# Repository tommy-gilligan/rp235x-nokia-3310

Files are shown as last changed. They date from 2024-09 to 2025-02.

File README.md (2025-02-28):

# Brique: RP235x Nokia 3310 Adapter Board

This started as a cute "what if?":

> What if I could type out messages on my smart phone by using tactile buttons like I used to have on my phone back in high school?

Because the board would need to fit into the chassis of a Nokia 3310 and because there are existing doodads that would be sitting alongside the board anyways, scope has crept to include connecting to these other thingamajigs.

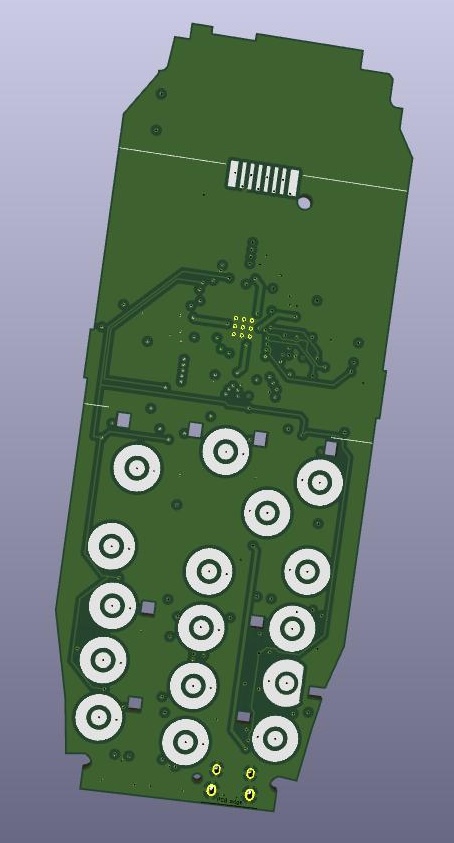
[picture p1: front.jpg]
3D render of front of adapter board

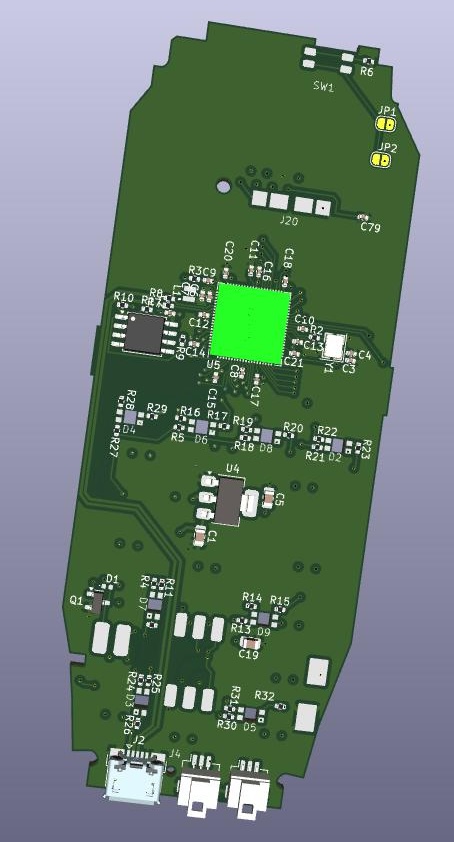
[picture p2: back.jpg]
3D render of back of adapter board


## [Simulation](https://tommy-gilligan.github.io/brique/simulation)
## [API](https://tommy-gilligan.github.io/brique/doc/shared)

## Setting up web environment

## Setting up rp environment

## Setting up board
### Ordering Board
### Disassemble 3310
### Install Hardware Test Program
### Reassemble 3310
### Manual Test
### Install Custom Software

### TODO
#### v0.3
- create example that plays RTTTL (and writes it to screen)
- Snake
- USB text entry

- power button (digital latch.  can this be triggered by 'any key'?  ie. any keypad press turns the device on.  there's enough GPIO to spare that we should have a dedicated GPIO for any key too)
- double check power regulation, boot button
- backlight LEDs (many options but prudent to go with whatever uses least power, is simplest.  use transistor to drive LED directly from battery/power)
- add back supercap rtc
- add jlcpcb part numbers, 3d models
- double check usb footprint
- pass more KiCAD checks in CI

- terse, unfriendly instructions (ie. README)
- document app API

#### Later
- make all system work live on primary core.  give apps dedicated secondary core.
- optional pico-w for wifi/bluetooth (using a module avoids need for recertification?)
    - looks like RP will release such a module (RM2) so go ahead with designing with that in mind
- detect battery type to refuse NiMH
- battery gauge
- mic connection
- use text_input for inputing secret for TOTP (drives the need for inputting numeric digits easily and RTC)
- power button used for BOOT/RUN?
- how should software versions synchronize with hardware versions. what level of compatibility should be supported.
- institute changelog
- use 'Issues' instead of README for tracking
- USB on simulated device
- optimise GPIO pin mapping.  shorten traces etc.
- connection plate for 3d printing
- increase flash capacity? i'd prefer to remove this part altogether by using rp2354 due for release later in the year
- bring more rigour to 'scheduler'

#### Much Later
- flex pcb for keypad?
- LTE modem?
- e-ink display?

https://serdisplib.sourceforge.net/ser/pcd8544.html

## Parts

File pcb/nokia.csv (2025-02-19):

Designator | Footprint | Comment | JLCPCB Part #
C12,C18,C11,C16,C22,C14,C2,C21,C17,C24,C13,C20,C15,C8,C79 | C_0402_1005Metric | 100n | C77020
C9,C6,C7,C10 | C_0402_1005Metric | 4.7u | C368809
C4,C3 | C_0402_1005Metric | 15p | C85891
C5,C1,C19 | C_0805_2012Metric | 10u | C17024
Y1 | Crystal_SMD_3225-4Pin_3.2x2.5mm | ABM8-272-T3 | C20625731
D1 | D_0402_1005Metric | Diode | C2837790
J3,J6 | JST_SH_SM03B-SRSS-TB_1x03-1MP_P1.00mm_Horizontal | SM03B-SRSS-TB | C160403
C23 | Kemet_FC_10.5X5.5 | 100m, 5V5 | DNF
L1 | L_pol_2016 | 3.3u | C42411119
Y2 | MicroCrystal_RV3028C7 | RV-3028-C7_32.768kHz_1ppm_TA_QC | C3019759
SW1 | power switch | SW_Push | C128539
R59,R58,R57,R56,R55,R54,R53,R52,R51,R50,R49,R48,R47,R46,R45,R44,R6 | R_0402_1005Metric | 3k | C137872
R35,R34,R38,R36 | R_0402_1005Metric | 10k | C60490
R10 | R_0402_1005Metric | 0 | C60485
R7,R8 | R_0402_1005Metric | 27 | C25100
R37 | R_0402_1005Metric | 120R | C114758
R39 | R_0402_1005Metric | 100k | C60491
R9,R1 | R_0402_1005Metric | DNF | DNF
R2 | R_0402_1005Metric | 1k | C25543
R3 | R_0402_1005Metric | 33 | C852729
R17 | R_0402_1005Metric | 100 ( ~90) | C106232
U5 | RP2350-QFN-80-1EP_10x10_P0.4mm_EP3.4x3.4mm_ThermalVias | RP2350_80QFN | C42415655
U1 | SOIC-8_5.23x5.23mm_P1.27mm | W25Q128JVS | C2999380
U4 | SOT-223-3_TabPin2 | NCP1117-3.3_SOT223 | C26537
Q1 | SOT-23 | BC847 | C391423
J2 | USB_Micro-B_Amphenol_10103594-0001LF_Horizontal | USB_B_Micro | C10418

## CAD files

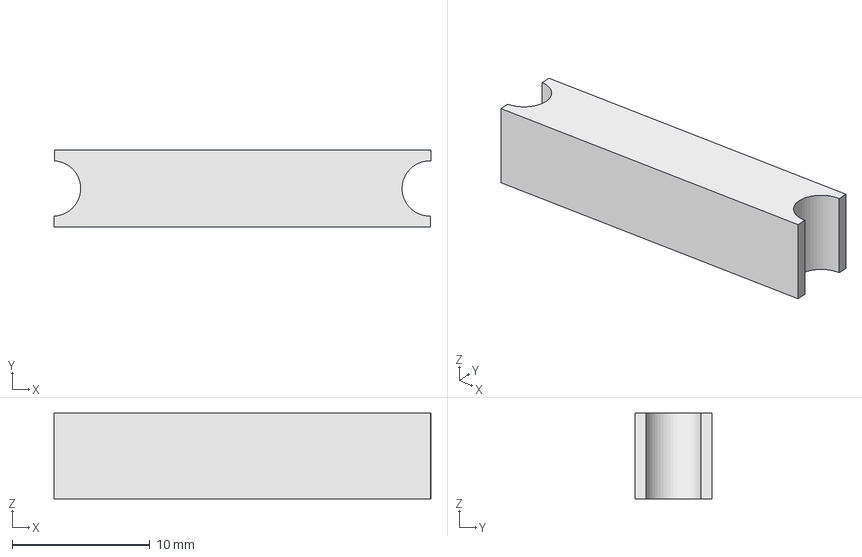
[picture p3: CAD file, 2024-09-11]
connection_plate.FCStd
27.3 x 5.61 x 6.20 mm

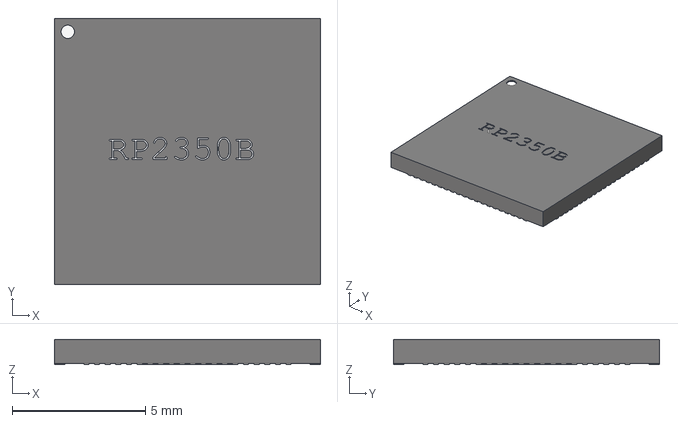
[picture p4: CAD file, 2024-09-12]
pcb/RP2350_QFN80.step
10.0 x 10.0 x 0.95 mm

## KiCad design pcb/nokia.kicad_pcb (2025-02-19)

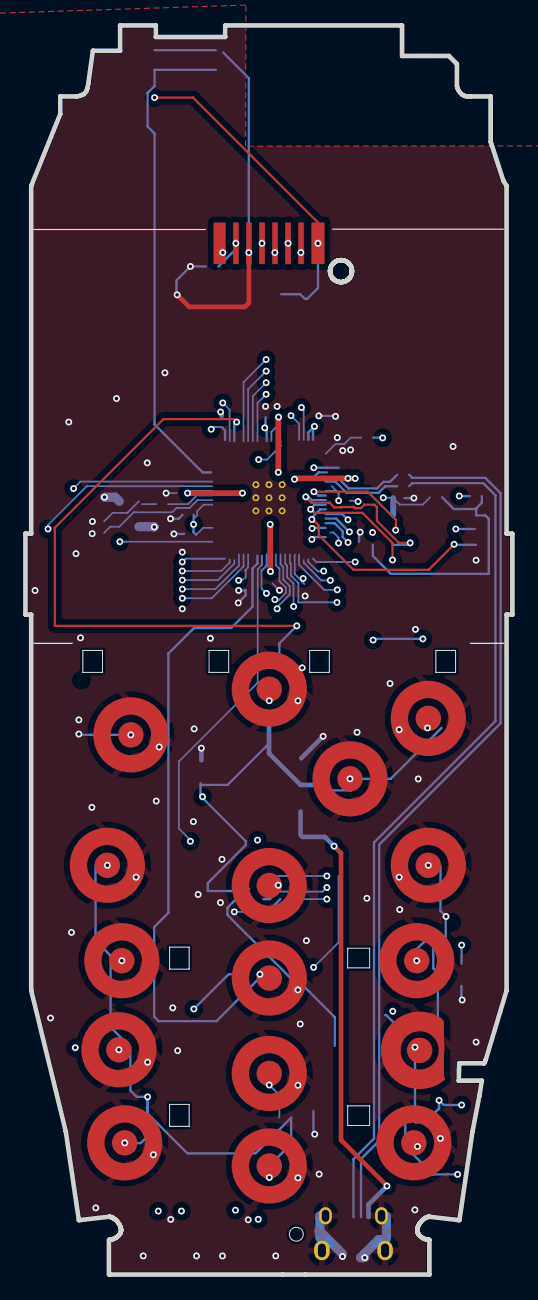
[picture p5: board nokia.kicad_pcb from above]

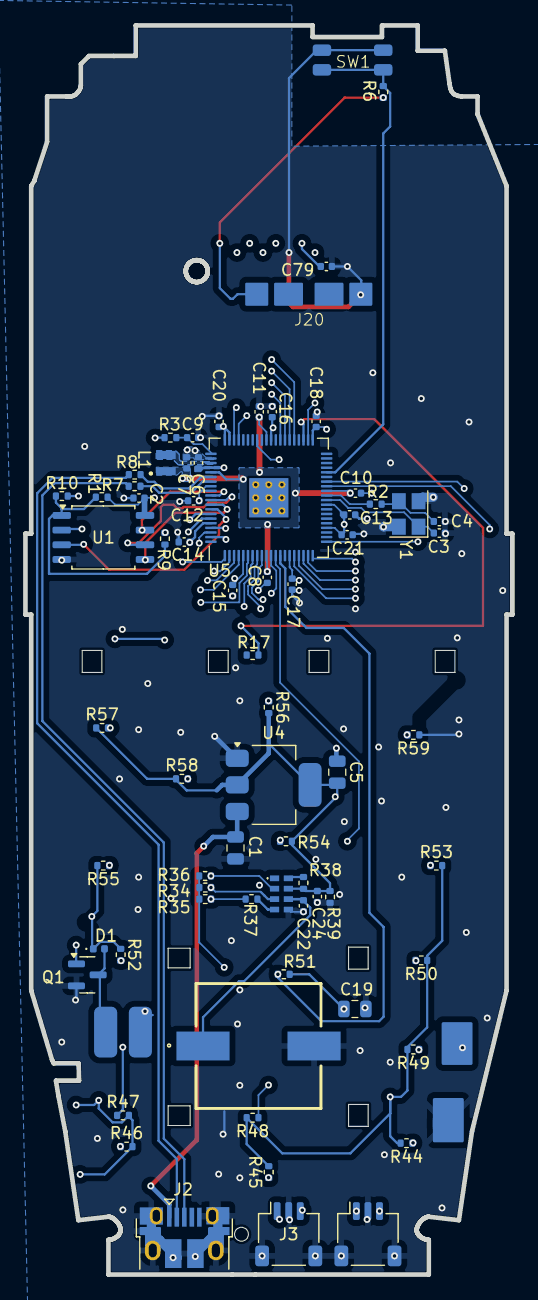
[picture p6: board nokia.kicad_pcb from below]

Board: 4 copper layers, 42.1 x 108.0 mm, 88 parts (71 on the bottom side), 57 nets.

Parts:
C1, C5, C19: 10u; C_0805_2012Metric
C2, C8, C11, C12, C13, C14, C15, C16, C17, C18, C20, C21, C22, C24: 100n; C_0402_1005Metric
C3, C4: 15p; C_0402_1005Metric
C6, C7, C9, C10: 4.7u; C_0402_1005Metric
C23: 100m, 5V5; Kemet_FC_10.5X5.5
C79: 100nF; C_0402_1005Metric
D1: D; D_0402_1005Metric
J1: Conn_01x07; screen
J2: USB_B_Micro; USB_Micro-B_Amphenol_10103594-0001LF_Horizontal
J3, J6: SM03B-SRSS-TB; JST_SH_SM03B-SRSS-TB_1x03-1MP_P1.00mm_Horizontal
J20: Conn_01x04_Pin; battery
KP0, KP1, KP2, KP4, KP5, KP6, KP7, KP8, KP9: Jumper_2_Open; ButtonPads
KP3: 3; ButtonPads
KP#1: Jumper_2_Open; ButtonPads
KP*1: Jumper_2_Open; ButtonPads
KPC1: C; ButtonPads
KPDOWN1: Jumper_2_Open; ButtonPads
KPSELECT1: Jumper_2_Open; ButtonPads
KPUP1: Jumper_2_Open; ButtonPads
L1: 3.3u; L_pol_2016
LS2: Buzzer; buzzer
M1: Vibration; vibrator
Q1: BC847; SOT-23
R1, R9: DNF; R_0402_1005Metric
R2: 1k; R_0402_1005Metric
R3: 33; R_0402_1005Metric
R6, R44, R45, R46, R47, R48, R49, R50, R51, R52, R53, R54, R55, R56, R57, R58, R59: 3k; R_0402_1005Metric
R7, R8: 27; R_0402_1005Metric
R10: 0; R_0402_1005Metric
R17: 90; R_0402_1005Metric
R34, R35, R36, R38: 10k; R_0402_1005Metric
R37: 120R; R_0402_1005Metric
R39: 100k; R_0402_1005Metric
SW1: SW_Push; power switch
U1: W25Q128JVS; SOIC-8_5.23x5.23mm_P1.27mm
U4: NCP1117-3.3_SOT223; SOT-223-3_TabPin2
U5: RP2350_80QFN; RP2350-QFN-80-1EP_10x10_P0.4mm_EP3.4x3.4mm_ThermalVias
Y1: ABM8-272-T3; Crystal_SMD_3225-4Pin_3.2x2.5mm
Y2: RV-3028-C7_32.768kHz_1ppm_TA_QC; MicroCrystal_RV3028C7

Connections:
+1V1: C7.1, C8.1, C10.1, C11.1, L1.1, U5.10 (DVDD), U5.32 (DVDD), U5.51 (DVDD), U5.65 (VREG_FB)
+3V3: C2.1, C5.1, C6.1, C12.1, C13.1, C14.1, C15.1, C16.1, C17.1, C18.1, C19.1, C20.1, C21.1, C24.1, D1.1 (K), J1.1, J20.1, M1.1 (+), R1.1, R3.1, R6.1, R34.1, R35.1, R36.1, R38.1, R39.1, R44.2, R45.2, R46.2, R47.2, R48.2, R49.2, R50.1, R51.1, R52.1, R53.2, R54.2, R55.2, R56.2, R57.1, R58.1, R59.1, U1.8 (VCC), U4.2 (VO), U5.5 (IOVDD), U5.15 (IOVDD), U5.24 (IOVDD), U5.29 (IOVDD), U5.41 (IOVDD), U5.50 (IOVDD), U5.59 (ADC_AVDD), U5.60 (IOVDD), U5.64 (VREG_VIN), U5.68 (USB_OTP_VDD), U5.69 (QSPI_IOVDD), U5.76 (IOVDD), Y2.7 (VDD)
/EVI: R38.2, Y2.8 (EVI)
/FLASH_SS: R1.2, R9.2, R10.2, U1.1 (~CS)
/GPIO0: J3.3, R9.1, U5.77 (GPIO0)
/GPIO1: J3.1, U5.78 (GPIO1)
/GPIO2: Q1.1 (B), U5.79 (GPIO2)
/GPIO4: KP#1.2 (B), R46.1, U5.1 (GPIO4)
/GPIO5: KP9.2 (B), R47.1, U5.2 (GPIO5)
/GPIO6: KP6.2 (B), R52.2, U5.3 (GPIO6)
/GPIO7: KP3.2 (B), R55.1, U5.4 (GPIO7)
/GPIO8: KPDOWN1.2 (B), R58.2, U5.6 (GPIO8)
/GPIO9: KPUP1.2 (B), R57.2, U5.7 (GPIO9)
/GPIO10: KP0.2 (B), R45.1, U5.8 (GPIO10)
/GPIO11: KP8.2 (B), R48.1, U5.9 (GPIO11)
/GPIO12: KPSELECT1.2 (B), R56.1, U5.11 (GPIO12)
/GPIO13: KP2.2 (B), R54.1, U5.12 (GPIO13)
/GPIO14: KP5.2 (B), R51.2, U5.13 (GPIO14)
/GPIO16: KPC1.2 (B), R59.2, U5.16 (GPIO16)
/GPIO17: KP1.2 (B), R53.1, U5.17 (GPIO17)
/GPIO18: KP4.2 (B), R50.2, U5.18 (GPIO18)
/GPIO19: KP7.2 (B), R49.1, U5.19 (GPIO19)
/GPIO20: KP*1.2 (B), R44.1, U5.20 (GPIO20)
/GPIO21: LS2.1, U5.21 (GPIO21)
/GPIO28: R6.2, SW1.2, U5.36 (GPIO28)
/GPIO33: J1.8, U5.42 (GPIO33)
/GPIO34: R17.1, U5.43 (GPIO34)
/GPIO36: J1.4, U5.45 (GPIO36)
/GPIO37: J1.5, U5.46 (GPIO37)
/GPIO38: J1.2, U5.47 (GPIO38)
/GPIO39: J1.3, U5.48 (GPIO39)
/QSPI_SCLK: U1.6 (CLK), U5.71 (QSPI_SCLK)
/QSPI_SD0: U1.5 (DI(IO0)), U5.72 (QSPI_SD0)
/QSPI_SD1: U1.2 (DO(IO1)), U5.74 (QSPI_SD1)
/QSPI_SD2: U1.3 (IO2), U5.73 (QSPI_SD2)
/QSPI_SD3: U1.7 (IO3), U5.70 (QSPI_SD3)
/QSPI_SS: R10.1, U5.75 (QSPI_SS)
/SCL: R34.2, U5.58 (GPIO47_ADC7), Y2.3 (SCL)
/SDA: R35.2, R37.2, U5.57 (GPIO46_ADC6)
/SWCLK: J6.1, U5.33 (SWCLK)
/SWD: J6.3, U5.34 (SWD)
/USB_D+: J2.3 (D+), R7.1
/USB_D-: J2.2 (D-), R8.1
/VREG_AVDD: C9.1, R3.2, U5.61 (VREG_AVDD)
/VREG_LX: L1.2, U5.63 (VREG_LX)
/XIN: C3.1, U5.30 (XIN), Y1.1
/XOUT: R2.1, U5.31 (XOUT)
/~INT: R36.2, U5.53 (GPIO42_ADC2), Y2.2 (~INT)
GND: C1.2, C2.2, C3.2, C4.2, C5.2, C6.2, C7.2, C8.2, C9.2, C10.2, C11.2, C12.2, C13.2, C14.2, C15.2, C16.2, C17.2, C18.2, C19.2, C20.2, C21.2, C22.2, C23.2, C24.2, C79.1, J1.6, J2.5 (GND), J2.6 (Shield), J3.2, J3.MP (MountPin), J6.2, J6.MP (MountPin), J20.4, KP0.1 (A), KP1.1 (A), KP2.1 (A), KP3.1 (A), KP4.1 (A), KP5.1 (A), KP6.1 (A), KP7.1 (A), KP8.1 (A), KP9.1 (A), KP#1.1 (A), KP*1.1 (A), KPC1.1 (A), KPDOWN1.1 (A), KPSELECT1.1 (A), KPUP1.1 (A), LS2.2, Q1.2 (E), R39.2, SW1.1, U1.4 (GND), U4.1 (GND), U5.62 (VREG_PGND), U5.81 (GND), Y1.2, Y1.4, Y2.5 (VSS)
unnamed: C4.1, R2.2, Y1.3
unnamed: D1.2 (A), M1.2 (-), Q1.3 (C)
unnamed: C79.2, J1.7
unnamed: R8.2, U5.66 (USB_DM)
unnamed: R7.2, U5.67 (USB_DP)
unnamed: R37.1, Y2.4 (SDA)
unnamed: C22.1, C23.1, Y2.6 (VBACKUP)
VBUS: C1.1, J2.1 (VBUS), U4.3 (VI)

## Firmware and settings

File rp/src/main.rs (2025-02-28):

#![no_std]
#![no_main]

#[unsafe(link_section = ".start_block")]
#[used]
pub static IMAGE_DEF: ImageDef = ImageDef::secure_exe();

// Program metadata for `picotool info`.
// This isn't needed, but it's recomended to have these minimal entries.
#[unsafe(link_section = ".bi_entries")]
#[used]
pub static PICOTOOL_ENTRIES: [embassy_rp::binary_info::EntryAddr; 6] = [
    embassy_rp::binary_info::rp_program_name!(c"rp235x-nokia-3310"),
    // in repo root: find pcb -type f \( -exec sha1sum "$PWD"/{} \; \) | awk '{print $1}' | sort | sha1sum | cut -b-10
    embassy_rp::binary_info::rp_pico_board!(c"rp235x-nokia-3310-5da11fc30e"),
    embassy_rp::binary_info::rp_program_description!(
        c"This example tests the RP Pico on board LED, connected to gpio 25"
    ),
    embassy_rp::binary_info::rp_cargo_version!(),
    embassy_rp::binary_info::rp_program_build_attribute!(),
    embassy_rp::binary_info::rp_program_url!(
        c"https://github.com/tommy-gilligan/rp235x-nokia-3310"
    ),
];

use core::cell::RefCell;

use assign_resources::assign_resources;
use defmt::unwrap;
use defmt_rtt as _;
use embassy_executor::{Executor, Spawner};
use embassy_rp::{
    bind_interrupts,
    block::ImageDef,
    multicore::{Stack, spawn_core1},
    peripherals,
    peripherals::USB,
    spi,
    spi::Spi,
    usb::InterruptHandler,
};
use embassy_sync::blocking_mutex::{Mutex, raw::NoopRawMutex};
use panic_probe as _;
use static_cell::StaticCell;

mod backlight;
mod button;
mod buzzer;
mod display;
mod keypad;
mod rtc;
mod usb;
mod vibration_motor;

assign_resources! {
    usbs: Usbs{
        usb: USB,
    }
}

bind_interrupts!(struct Irqs {
    USBCTRL_IRQ => InterruptHandler<USB>;
});

static mut CORE1_STACK: Stack<4096> = Stack::new();
static EXECUTOR1: StaticCell<Executor> = StaticCell::new();

#[embassy_executor::main]
async fn main(_spawner: Spawner) {
    let p = embassy_rp::init(Default::default());
    let r = split_resources!(p);
    spawn_core1(
        p.CORE1,
        unsafe { &mut *core::ptr::addr_of_mut!(CORE1_STACK) },
        move || {
            let executor1 = EXECUTOR1.init(Executor::new());
            executor1.run(|spawner| unwrap!(spawner.spawn(usb::big_usb_task(spawner, r.usbs))));
        },
    );

    let mut power = button::Button::new(p.PIN_28);

    let mut vibration_motor = vibration_motor::Motor::new(p.PIN_2);
    let mut buzzer = buzzer::Beeper::new(p.PWM_SLICE2, p.PIN_21);
    let mut clock = rtc::Clock::new(p.I2C1, p.PIN_46, p.PIN_47);

    let mut display_config = spi::Config::default();
    display_config.frequency = 4_000_000;
    let spi_bus: Mutex<NoopRawMutex, _> = Mutex::new(RefCell::new(Spi::new_blocking(
        p.SPI0,
        p.PIN_38,
        p.PIN_39,
        p.PIN_32,
        display_config,
    )));
    let mut display = display::Display::new(&spi_bus, p.PIN_37, p.PIN_36, p.PIN_33);

    let mut keypad = keypad::ContactKeypad::new(
        p.PIN_16, p.PIN_12, p.PIN_9, p.PIN_8, p.PIN_17, p.PIN_13, p.PIN_7, p.PIN_18, p.PIN_14,
        p.PIN_6, p.PIN_19, p.PIN_11, p.PIN_5, p.PIN_20, p.PIN_10, p.PIN_4,
    );

    let mut backlight = backlight::Light::new(p.PIN_15);

    let items = ["Clock", "Hardware Test", "Keyboard"];
    let mut menu = shared::menu::Menu::new(&items);

    loop {
        let i = loop {
            if let Some(index) = menu.process(&mut keypad, &mut display).await {
                break index;
            }
        };
        if i == 0 {
            let clock_app = clock::Clock;
            match shared::run_app(
                clock_app,
                &mut vibration_motor,
                &mut buzzer,
                &mut display,
                &mut keypad,
                &mut clock,
                &mut backlight,
                &mut power,
                usb::RX_CHANNEL.try_receive().ok(),
            )
            .await
            {
                Some(shared::UsbTx::HidChar(c)) => usb::HID_TX_CHANNEL.send(c).await,
                Some(shared::UsbTx::CdcBuffer(b)) => usb::CDC_TX_CHANNEL.send(b).await,
                None => {}
            }
        } else if i == 2 {
            let keyboard = keyboard::Keyboard;
            match shared::run_app(
                keyboard,
                &mut vibration_motor,
                &mut buzzer,
                &mut display,
                &mut keypad,
                &mut clock,
                &mut backlight,
                &mut power,
                usb::RX_CHANNEL.try_receive().ok(),
            )
            .await
            {
                Some(shared::UsbTx::HidChar(c)) => usb::HID_TX_CHANNEL.send(c).await,
                Some(shared::UsbTx::CdcBuffer(b)) => usb::CDC_TX_CHANNEL.send(b).await,
                None => {}
            }
        } else {
            let hardware_test = hardware_test::HardwareTest::default();
            match shared::run_app(
                hardware_test,
                &mut vibration_motor,
                &mut buzzer,
                &mut display,
                &mut keypad,
                &mut clock,
                &mut backlight,
                &mut power,
                usb::RX_CHANNEL.try_receive().ok(),
            )
            .await
            {
                Some(shared::UsbTx::HidChar(c)) => usb::HID_TX_CHANNEL.send(c).await,
                Some(shared::UsbTx::CdcBuffer(b)) => usb::CDC_TX_CHANNEL.send(b).await,
                None => {}
            }
        }
    }
}

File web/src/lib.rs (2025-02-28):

#![allow(unexpected_cfgs)]
mod backlight;
mod buzzer;
mod display;
mod keypad;
mod power;
mod rtc;
mod vibration_motor;

use embassy_executor::Spawner;

#[embassy_executor::main]
async fn main(_spawner: Spawner) {
    wasm_logger::init(wasm_logger::Config::default());

    let window = web_sys::window().expect("no global `window` exists");
    let document = window.document().expect("should have a document on window");
    let svg = document.get_element_by_id("svg1").unwrap();
    let mut vibration_motor = vibration_motor::Motor::new(svg);

    let svg = document.get_element_by_id("nokia").unwrap();
    let mut buzzer = buzzer::Buzzer::new(svg);
    let mut rtc = rtc::Clock::new();

    let svg = document.get_element_by_id("display").unwrap();
    let mut display = display::Display::new(svg);

    let svg = document.get_element_by_id("backlight").unwrap();
    let mut light = backlight::Light::new(svg);

    let mut keypad = keypad::DomKeypad::new(
        "cancel", "select", "up", "down", "one", "two", "three", "four", "five", "six", "seven",
        "eight", "nine", "asterisk", "zero", "hash",
    );

    let mut power = power::DomPower::new("power");

    let items = ["Clock", "Hardware Test"];
    let mut menu = shared::menu::Menu::new(&items);
    loop {
        let i = loop {
            if let Some(index) = menu.process(&mut keypad, &mut display).await {
                break index;
            }
        };
        if i == 0 {
            let clock = clock::Clock;
            shared::run_app(
                clock,
                &mut vibration_motor,
                &mut buzzer,
                &mut display,
                &mut keypad,
                &mut rtc,
                &mut light,
                &mut power,
                None,
            )
            .await;
        } else {
            let hardware_test = hardware_test::HardwareTest::default();
            shared::run_app(
                hardware_test,
                &mut vibration_motor,
                &mut buzzer,
                &mut display,
                &mut keypad,
                &mut rtc,
                &mut light,
                &mut power,
                None,
            )
            .await;
        }
    }
}

use core::cell::RefCell;
use std::rc::Rc;

use wasm_bindgen::{JsCast, closure::Closure};

struct DomB {
    was_clicked: bool,
}

impl DomB {
    #[allow(clippy::too_many_arguments)]
    fn new(id: &'static str) -> Rc<RefCell<Self>> {
        let window = web_sys::window().expect("no global `window` exists");
        let document = window.document().expect("should have a document on window");
        let s = Self { was_clicked: false };
        let r = Rc::new(RefCell::new(s));
        let g = r.clone();

        let closure = Closure::<dyn FnMut(_)>::new(move |_event: web_sys::MouseEvent| {
            (*g).borrow_mut().was_clicked = true;
        });

        document
            .get_element_by_id(id)
            .unwrap()
            .add_event_listener_with_callback("mousedown", closure.as_ref().unchecked_ref())
            .unwrap();

        closure.forget();

        r
    }

    fn check(&mut self) -> bool {
        let result = self.was_clicked;
        self.was_clicked = false;
        result
    }
}

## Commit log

2024-08-25 first (public) iteration of board
    [nokia.kicad_pcb, nokia.kicad_sch]
2024-08-25 add 3d preview of board
2024-09-06 2nd iteration of board
    [nokia.kicad_pcb, nokia.kicad_sch]
2024-09-06 Revert "more sound"
    This reverts commit 2d6fc62123d8b8c26e3f52d195ee75382c64a918.
    [lib.rs, main.rs]
2024-09-09 add breakout connector
    [nokia.kicad_pcb, nokia.kicad_sch]
2024-09-12 update readme, renders
    [RP2350_QFN80.step, nokia.kicad_pcb]
2024-09-16 improve display driver
2024-09-16 cleanup and start adding virtual
    [RP2350_QFN80.step, nokia.kicad_pcb, nokia.kicad_sch]
2024-09-17 power button can be gpio or run
    [nokia.kicad_pcb, nokia.kicad_sch]
2024-09-29 fix and refactor snake, format
    [buzzer.rs, display.rs, lib.rs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]
2024-10-09 make corrections
    [bom.csv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]
2024-10-10 switch to 235xa
2024-11-15 fix clearance for screws, more space for connectors, move LEDs
    [nokia.kicad_pcb, nokia.kicad_sch]
2024-11-15 remove prototyping connector
    [nokia.kicad_pcb, nokia.kicad_sch]
2024-11-15 remove display cap jumper
    [nokia.kicad_pcb, nokia.kicad_sch]
2024-11-16 update renders, use zone for 1v1 net
    [nokia.kicad_pcb]
2024-11-27 add rtc and gauge, regulator
    [nokia.kicad_pcb, nokia.kicad_sch]
2024-11-29 first version of pcb with 2350 finished
    [bom.csv, nokia.kicad_pcb]
2025-02-19 pcb v0.2
    [nokia-B_Cu.gbl, nokia-B_Mask.gbs, nokia-B_Paste.gbp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]
2025-02-25 update software for board v0.1
2025-02-25 make apps interruptible, give access to display
